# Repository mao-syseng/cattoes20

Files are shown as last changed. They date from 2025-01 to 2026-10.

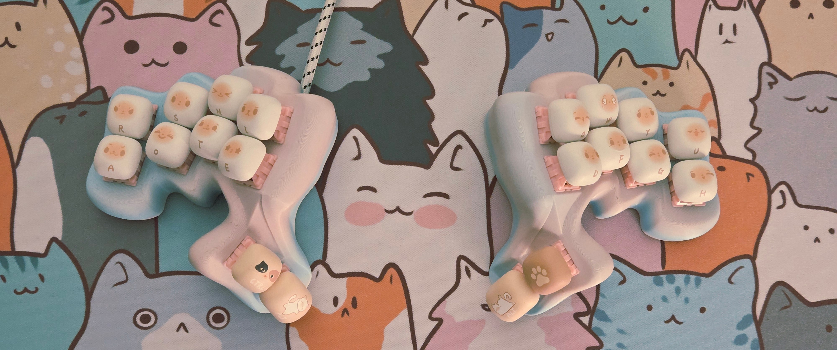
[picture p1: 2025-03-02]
assets/cattoes.jpg

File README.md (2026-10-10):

# cat⋅toes20
cat⋅toes20 – A sculpted, one-handed keyboard with 10 keys. Designed for individuals with limited hand mobility or those who use only one hand, including those with monoplegia, hemiparesis, amputations, or other conditions. Its ergonomic design ensures comfort and accessibility for efficient, one-handed input.

https://mao-syseng.github.io/cattoes20/

## Parts
- 10x choc switches
- 10x 1N4148 Signal Diodes
- seeed studio xiao rp2040 mcu
- 22AWG solid core wire
- 3D printed case - I would recommend using 100% infill to add some weight to it.
- Some rubber tabs on the bottom of the case to avoid slipping.

## Layout
- Taipo https://inkeys.wiki/en/keymaps/taipo
- There is interactive version of the layout here: https://mao-syseng.github.io/monopleg10/

## Site notes
- https://news.ycombinator.com/item?id=42814110
- Make something to show how to use the layout

## soldering notes
- solder columns first
- columns should be low and rows high, no need for much insulation due to low amount of wires.

## V1.1
- 5mm walls instead of 2mm
- 100% infill to add weight
- skip the bottom plate and add dutter on the case edges.
- use seeed studio xiao rp2040, Pi Pico was too big.
- add hole for wire

## Firmware notes
- hold boot button while plugging in to laptop
- drag and drop CircuitPython to the microcontroller. Remember to get correct circuitpython version for the board.
- Drag and drop KMK folder to the board.
- Edit code.py accordingly

## KMK Notes
First working version of simple KMK config!! has all base chords
```
import board

from kmk.kmk_keyboard import KMKKeyboard
from kmk.keys import KC
from kmk.scanners import DiodeOrientation
from kmk.modules.combos import Combos, Chord, Sequence

keyboard = KMKKeyboard()
combos = Combos()
keyboard.modules.append(combos)

keyboard.col_pins = (board.D4, board.D5, board.D9, board.D8)
keyboard.row_pins = (board.D1, board.D10, board.D3)
keyboard.diode_orientation = DiodeOrientation.ROW2COL

keyboard.keymap = [
    [KC.I, KC.N, KC.S, KC.R,
     KC.E, KC.T, KC.O, KC.A,
     KC.BSPC, KC.SPC, KC.NO, KC.NO]
]

combos.combos = [
    Chord((KC.R, KC.S), KC.B),
    Chord((KC.N, KC.I), KC.Y),
    Chord((KC.T, KC.E), KC.H),
    Chord((KC.A, KC.O), KC.L),
    Chord((KC.S, KC.N), KC.P),
    Chord((KC.O, KC.T), KC.U),
    Chord((KC.R, KC.I), KC.G),
    Chord((KC.A, KC.E), KC.D),
    Chord((KC.R, KC.N), KC.Z),
    Chord((KC.S, KC.I), KC.F),
    Chord((KC.A, KC.T), KC.Q),
    Chord((KC.O, KC.E), KC.C),
    Chord((KC.R, KC.T), KC.X),
    Chord((KC.O, KC.I), KC.K),
    Chord((KC.S, KC.E), KC.V),
    Chord((KC.N, KC.A), KC.J),
    Chord((KC.R, KC.E), KC.M),
    Chord((KC.A, KC.I), KC.W),
]

if __name__ == '__main__':
    keyboard.go()

```

## Cosmos 
V2 cosmos config: https://ryanis.cool/cosmos/beta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 

V3 : https://ryanis.cool/cosmos/beta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

V3 MX: https://ryanis.cool/cosmos/beta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

V4 MX from 30 to 25 tenting, lower pinkie, higher thumb, with screw for plate: https://ryanis.cool/cosmos/beta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

V5, improved spacing, optimized for MOG profile keycaps: https://ryanis.cool/cosmos/beta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

V6, back to choc since it is easier to type on. Improved spacing and rounded edges: https://ryanis.cool/cosmos/beta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

V7, back to mx after a year. V6 might be better but would like to make mx switches work. will try lighter switches and cherry keycaps. MOG keycaps look cool but are not comfortable to type on. 
https://ryanis.cool/cosmos/beta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

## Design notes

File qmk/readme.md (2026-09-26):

# Pico Chord 10

A custom 10-key chorded keyboard based on the Raspberry Pi Pico H / RP2040.

## QMK folder structure
```
qmk_firmware/
└── keyboards/
    └── pico_chord10/
        ├── keyboard.json
        ├── rules.mk
        ├── readme.md
        └── keymaps/
            └── default/
                └── keymap.c
```

## QMK Build
`qmk compile -kb pico_chord10 -km default`
You should get an RP2040 .uf2 firmware file.

For flashing, put the Pico into its USB bootloader by holding BOOTSEL while plugging it into USB. The Pico will appear as the RPI-RP2 drive; copy the .uf2 file to it

## Hardware

- Raspberry Pi Pico H
- 10 switches
- Each switch connected directly between a GPIO and GND
- No matrix diodes required

## GPIO assignment

| Key | GPIO |
|-----|---|
| 1 | GP1 |
| 2 | GP2 |
| 3 | GP3 |
| 4 | GP4 |
| 5 | GP5 |
| 6 | GP6 |
| 7 | GP7 |
| 8 | GP8 |
| 9 | GP9 |
| 10 | GP10 |

## Layout

    I  N  S  R
    E  T  O  A
    BSPC SPC

## Combos

    R + S = B
    N + I = Y
    T + E = H
    A + O = L
    S + N = P
    O + T = U
    R + I = G
    A + E = D
    R + N = Z
    S + I = F
    A + T = Q
    O + E = C
    R + T = X
    O + I = K
    S + E = V
    N + A = J
    R + E = M
    A + I = W

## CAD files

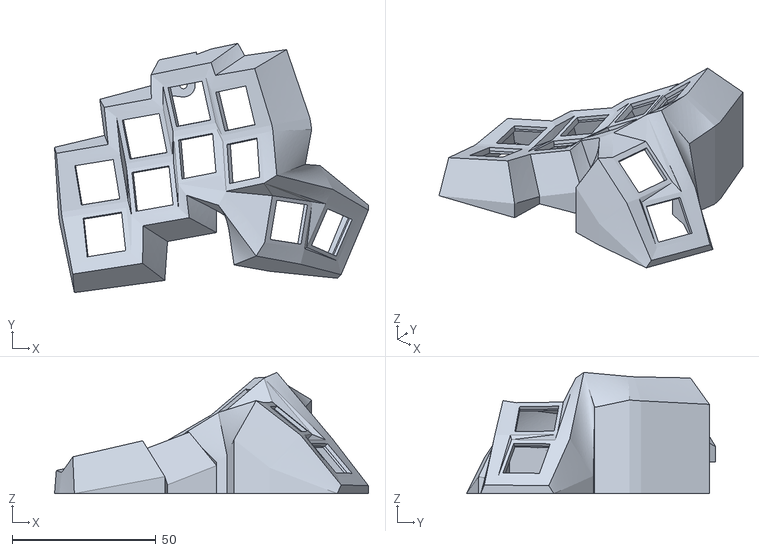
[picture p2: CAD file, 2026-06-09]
assets/cattoes10-caseleft.stl
109.1 x 86.6 x 42.1

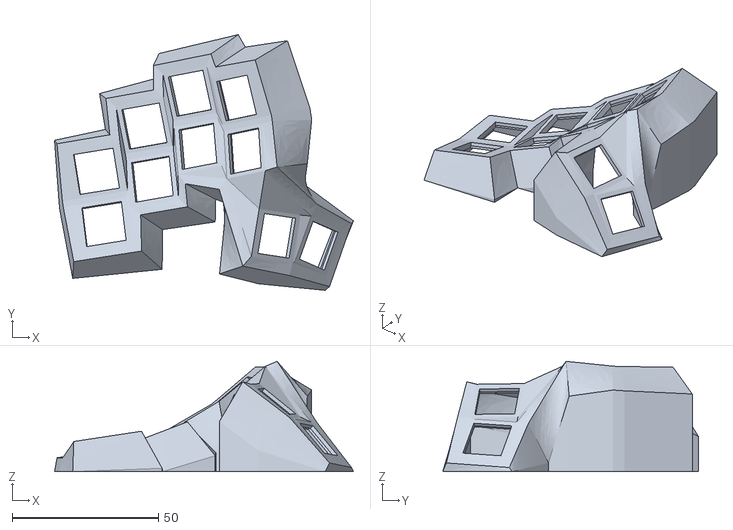
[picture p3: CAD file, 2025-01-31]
assets/cat-toes-case.stl
102.4 x 87.5 x 37.8

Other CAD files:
assets/cattoes10-caseright(1).stl

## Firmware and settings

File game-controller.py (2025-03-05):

import board

from kmk.kmk_keyboard import KMKKeyboard
from kmk.keys import KC
from kmk.scanners import DiodeOrientation
from kmk.modules.combos import Combos, Chord, Sequence
from kmk.modules.mouse_keys import MouseKeys


keyboard = KMKKeyboard()
combos = Combos()
keyboard.modules.append(combos)
keyboard.modules.append(MouseKeys())

keyboard.col_pins = (board.D4, board.D5, board.D9, board.D8)
keyboard.row_pins = (board.D1, board.D10, board.D3)
keyboard.diode_orientation = DiodeOrientation.ROW2COL

keyboard.keymap = [
       [KC.MB_LMB, KC.X, KC.Z, KC.R,
     KC.E, KC.A, KC.S, KC.A,
     KC.MB_LMB, KC.MB_LMB, KC.NO, KC.NO]
]

combos.combos = [
    Chord((KC.X, KC.Z), KC.NO),
]

if __name__ == '__main__':
    keyboard.go()
